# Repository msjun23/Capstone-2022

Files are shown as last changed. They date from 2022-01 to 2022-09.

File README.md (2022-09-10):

# Capstone-2022
Capstone Design at Kwangwoon Univ. 2022

# UMRobot (a.k.a. UMbot)
Universal Mobile Robot Project

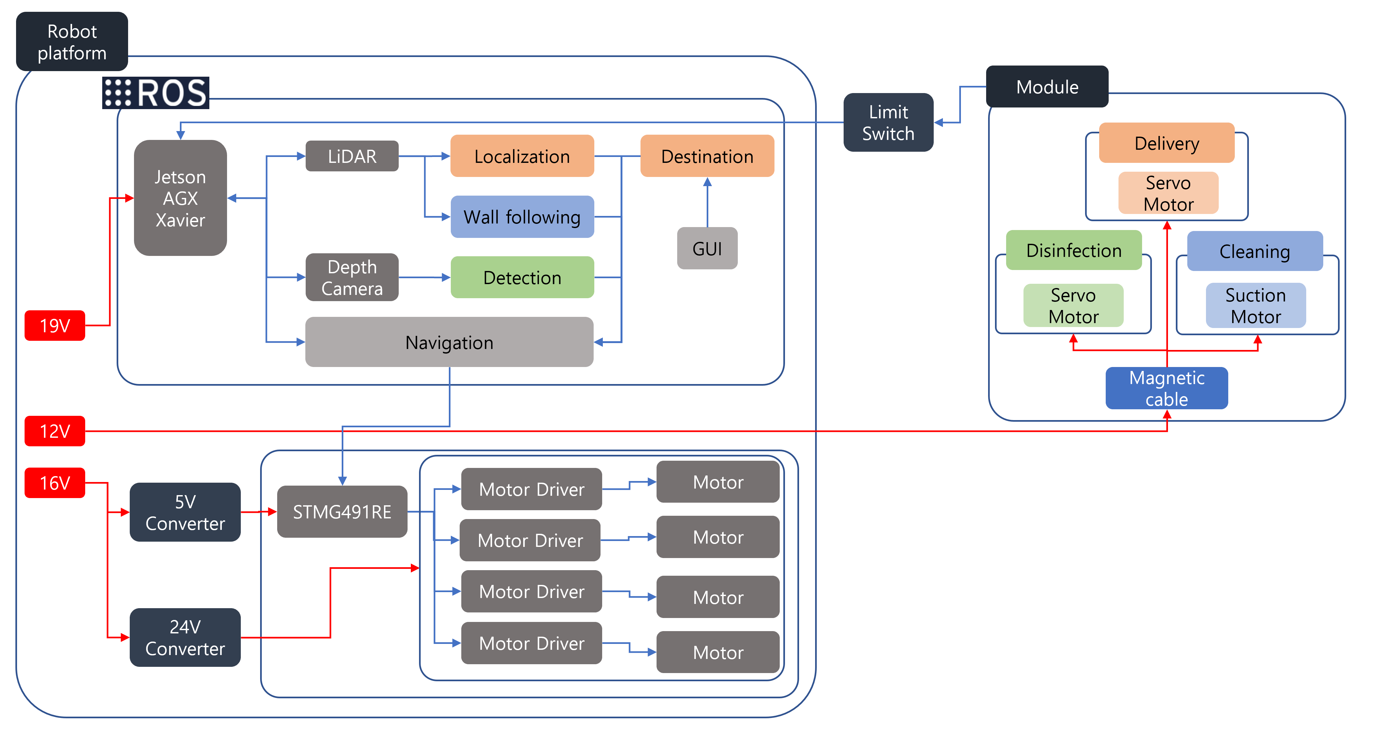
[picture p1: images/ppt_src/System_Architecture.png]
sys_arch


# Git repository
- [ROS Gazebo Simulation](https://github.com/msjun23/umrobot_description)
- [ROS & YOLOv5](https://github.com/msjun23/yolov5_ros)
- [Get door info & pose using camera and LiDAR](https://github.com/csw609/door_angle)
- [Wall following algorithm](https://github.com/msjun23/wall_following)
- [Modules](https://github.com/msjun23/umbot-modules)

# Adviser
[**Junghyun Oh**](http://robotailab.net/people/junghyunoh.html), Prof.
> [RAIL(Robotics & A.I. Lab.)](http://robotailab.net/index.html)
>
> Assistant Professor, School of Robotics, Kwangwoon University

# Team
## HW
- [**Jaewoo Jang**](https://github.com/wodnek1996): Team leader, Motor Control
- [**Taegyeom Gim**](https://github.com/GYEOMGYEOM): Design
## SW
- [**Seokwon Choi**](https://github.com/csw609): SLAM
- [**Seokjun Moon**](https://github.com/msjun23): Detection

---

# Paper
**장재우, 최석원, 문석준, 김태겸, 오정현, "모듈 장착형 다용도 로봇 플랫폼", ICROS2022, Geoje, Korea (Jun.2022) - Poster**

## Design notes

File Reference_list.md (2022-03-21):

# Paper
- [A Comparison of Path Planning Algorithms for Robotic Vacuum Cleaners](https://kth.diva-portal.org/smash/get/diva2:1214422/FULLTEXT01.pdf)
- [Path planning algorithm development for autonomous vacuum cleaner robots](https://www.researchgate.net/publication/269297110_Path_planning_algorithm_development_for_autonomous_vacuum_cleaner_robots)
- [Experience based Domestic Environment and User Adaptive Cleaning Algorithm of a Robot Cleaner](https://ieeexplore.ieee.org/stamp/stamp.jsp?tp=&arnumber=7057525)

# Video link
- [협업을 위한 모바일 로봇](https://www.youtube.com/watch?v=IeyBXzikhD0)

- [메카넘 휠 구동 영상](https://www.youtube.com/watch?v=_tmiu1wpp_E)

- [CES2022 현대차 MobeD](https://www.youtube.com/watch?v=KeVDFvYofks)

- [로봇 청소기 예제: 양정연 교수님 SLAM 수업](https://www.youtube.com/watch?v=VXVn75VXRMM&list=PL3Ax8f2laJ6vU449FdgWlVl2VtizhDIfj&index=13)

# Parts
## Jetson AGX Xavier
[Spec & Documentation](https://developer.nvidia.com/embedded/jetson-agx-xavier-developer-kit)

[Tech Blog](https://developer.nvidia.com/blog/nvidia-jetson-agx-xavier-32-teraops-ai-robotics/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)

[NVIDIA Tutorial](https://developer.nvidia.com/embedded/learn/tutorials)

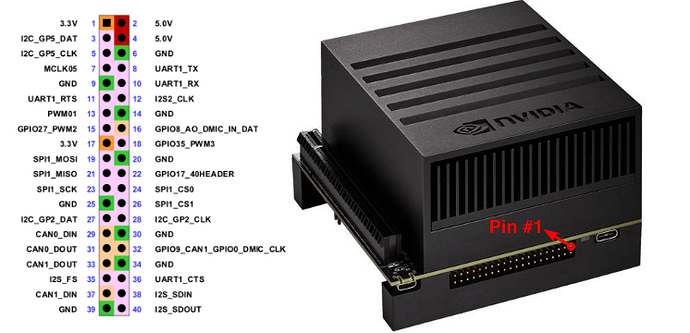
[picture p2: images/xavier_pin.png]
xavier_pin


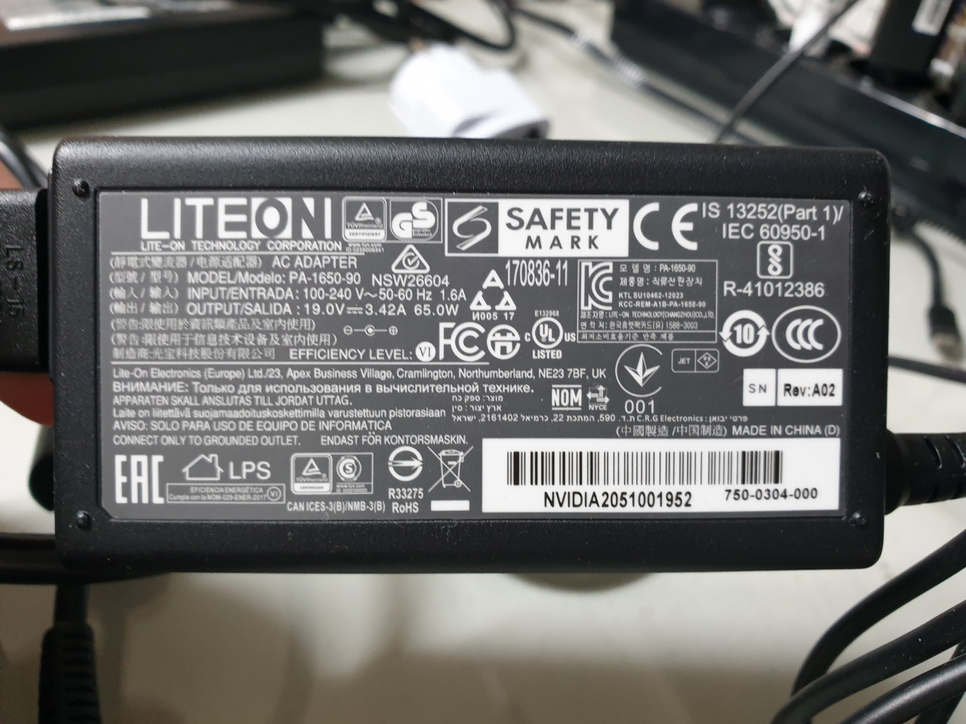
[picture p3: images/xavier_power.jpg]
xavier_power


## Motor
- [IG42GM 02type 24V](https://www.devicemart.co.kr/goods/view?no=1326531)
- 감속비: 1/61
- 18kg-cm // 110PRM // Rated current: 2100mA

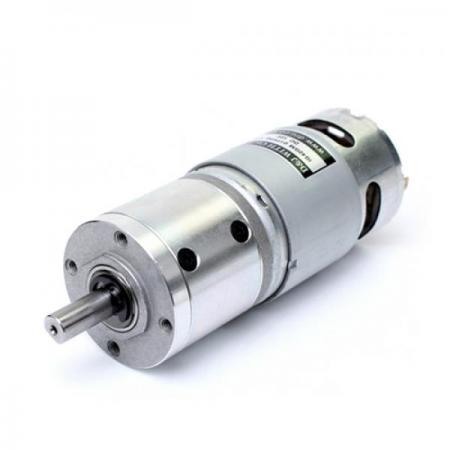
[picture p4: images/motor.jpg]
motor


## Motor Driver
[DCMD-100-P](https://www.devicemart.co.kr/goods/view?no=1266131)

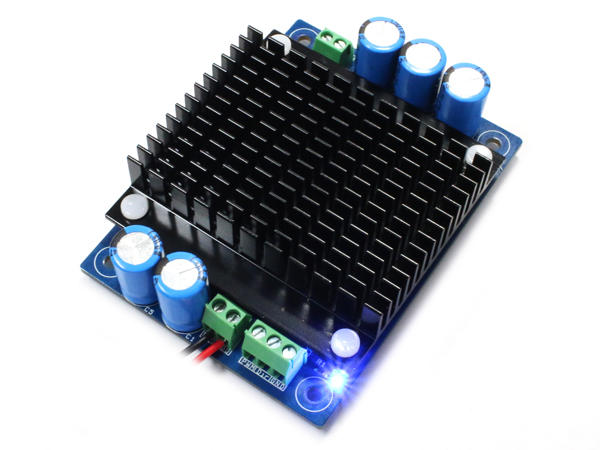
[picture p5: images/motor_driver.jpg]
motor_driver


## Battery
- Jetson
> [노트북 배터리](http://item.gmarket.co.kr/Item?goodscode=1267373161)

- Motor
> 12V, 7400mA, 55C
>
> 12V -> 24V 승압 회로 필요

# Contest Info
## [SRC IRC](http://www.seoultechrobot.com/index.php)

## [KWIX](https://ei.kw.ac.kr/kwix/kwix_18.php)
- 오정현 교수님

## [한이음 ICT멘토링](https://www.hanium.or.kr/portal/hanium/businessOverview.do)
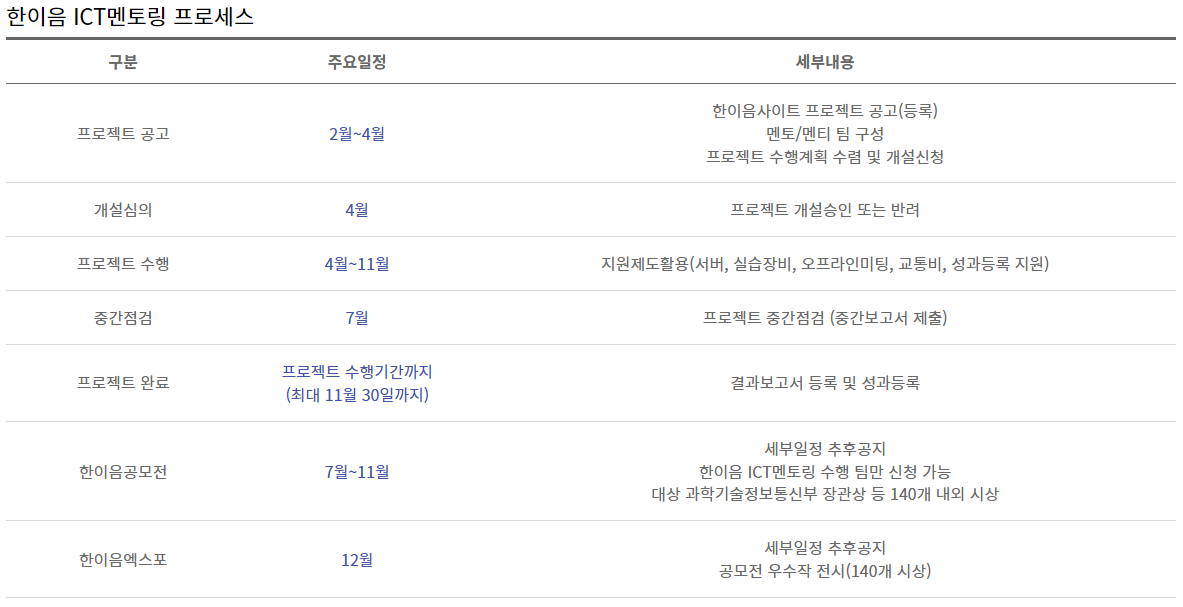
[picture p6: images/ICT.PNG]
ICT


- 멘토: 용호형

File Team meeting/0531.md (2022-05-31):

# 5월 31일

# 최석원, 문석준

- 맵 보안 완료
- 로컬라이제이션 완료
- 방역 모듈 경로 생성까지는 완료
- Jetson AGX Xavier GPIO 세팅 완료
- To do List
    - 방역 모듈 fine control
    - 배달 모듈 실험
    - 청소 모듈 실험

# 장재우

- 모듈 전원 공급 회로 설계 완료
- To do List
    - 모듈별 회로(GPIO, 전원 등) + 아두이노, 모터 등 제작

# 김태겸

- 모듈별 출력 완료
- 로봇 플랫폼에 마그네틱 케이블 설치
- To do List
    - 모듈에 마그네틱 케이블 설치
    - 디스플레이 설치
    - 리미트 스위치 설치
    - 청소 모듈 조립(파이프)

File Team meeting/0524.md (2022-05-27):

# 5월24일

# 김태겸

- 파이프 구매 완료(쉐챌)
- 청소 모듈 포함해서 3D 프린터 뽑을 거 있는데 꽤 오래 걸릴 듯(진행 중)
- To do List
    - 가공 및 조립
    - 마그네틱 설치
    - 디스플레이 설치
    - 리미트 스위치

# 문석준 & 최석원

- 맵 제작
- Vins-Fusion으로 odometry 제작
- 로컬라이제이션 알고리즘 시험
- 어셈블 중
- To do List
    - 맵 보완
    - 로컬라이제이션
    - 방역 모듈(SW) 실험
    - 배달 모듈(SW) 실험
    - 청소 모듈(SW) 실험

# 장재우

- 패킷 통신 완료
- To Do List
    - 모듈 전원 공급 회로 설계

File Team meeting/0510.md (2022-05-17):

# 문석준

- jetson 초기화, 복구 완
- 내비게이션 완
- 매핑 잘돼고
- 석원이랑 합치면 될듯
- 골 포인트를 UI 에서 좌표 형태로 pub하도록 하면 됨
- detection부 디버깅 중(해결하면 위 사안으로 넘어갈 예정)

# 최석원

- 방역 모듈, 기존 모듈 디버깅
- 석준이랑 합치기
- outlier 제거는 문 인식x → 문고리 인식 후 실험 필요
- 로봇 완성 후 실험 필요

# 겸겸스

- 방역, 배달 모듈 부품 가공 중(파츠 나눠서)
- 서스펜션: 수정 필요(재가공)
- 카메라 마운트, 디스플레이 마운트 회사에서 가공 예정

# 장재우

- 전류 제어 이슈
- 전류 제어 → 속도 제어

# To Do

- SW 융합 및 디버깅
- 제어 이슈 처리

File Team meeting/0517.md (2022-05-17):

# 장재우

- 제어기 완료
- To do list : ROS to stm32 board
- To  do list : 19일 이후 모듈 전원 공급

# 문석준

- 방역모듈 3D 프린터 다 뽑앗고
- To do list: 어샘블해야 됨
- To do list : 아두이노 만져보기

# 최석원

- 소프트웨어 진행사항은 없음
- 실험 도움, 메카넘 휠 바퀴 망가진 것들 고침
- To  do list : 맵 제작, 알고리즘들 로봇에서 테스트

# 김태겸

- 5월 17일 : 배선 정리, 라이다, 카메라
- 5월 18일 : 파이프 구매
- 5월 19일 : 마그네틱 설치
- 주말까지 : 디스플레이(VESA 규격: 75 * 75)  마운트 설계
- 주말까지 : 청소 모듈 설계
- 서스펜션은 제작 취소 // 완성 후 서스펜션 추가

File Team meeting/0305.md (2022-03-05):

# KWIX
- 개인 서명 필요

# 한이음 ICT 멘토링
- 멘토 정하기

# 일정
재우-월화수목금토일
석준-월화수 (토일 간헐적)
석원-월화수 (토일 간헐적)
겸겸-화목 (부르면 옴)

# 석준
- 문과 작업
- 프로젝트 

# 겸겸스
- 서스펜션 설계까지 완
- 로빛이랑 얘기해서 담주나 다담주 쯤 가공 시작
- 이번 달 안까지 메인 완성 목표

# 석원
- Point cloud -> 필터링 후 평면의 방정식 구함
- ROS 상에서 GUI 구현

기능은 어렵지 않을 듯

# 재우형
- IG42GM 02type 24V
- encoder 바꿀 수도 있음

# To Do & Consider
- 문, 문고리 detection 후 위치 pub, 수요일 쯤 석원, 석준 퓨전 목표
- 담주나 다담주 쯤 가공 시작 (3월 10일 쯤?)
- 겸겸스가 모터까지 추가해서 모델링
- 석준: 청소 모듈 path planning 조사
- 전체 회로 제작
- 캡스톤 비 구매
- wasd -> 모터 제어
- 다음 교수회의는 14, 15, 16?

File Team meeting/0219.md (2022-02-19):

# 재우형
- Jetson Xavier -> 노트북 보조 배터리 (10만원)
- 24V 배터리(~20만원)
- 12V 배터리면 좀 만만함
- ~~엘리베이터~~
- Dynamics 진행 중

---

- load 20kg
- 메카넘휠 radius
- torque 48kg-cm는 나와야 여유로울 듯

## 범수형네
- 캡스톤 load < 8kg

# 겸겸
- new 설계 중
- AK80 안됨

# 석원
- RGB 이미지 상에서 bounding box 전달 받아서 point cloud 상에서 crop(?), plane segmentation

# 석준
- 문 데이터 셋 찾기
- 문 데이터 vs 문고리 데이터 셋
- segmentation도 한 번 고려만 해보면 좋을 듯

# To Do & Consider
- 24일 날 교수님 미팅 잡아봄
- 임베디드 프로그래밍(하위 제어)
- **모터 선정**
- **사비 털어야 됨**
- **모터 하나 ~20만원 정도**
- 각자 개인 계획표 세워오기
- 개인 계획 조율 -> 전체 계획

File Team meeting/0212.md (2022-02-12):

# 재우형
- 메카넘휠 dynamics 해석

로봇운동학 짱짱맨

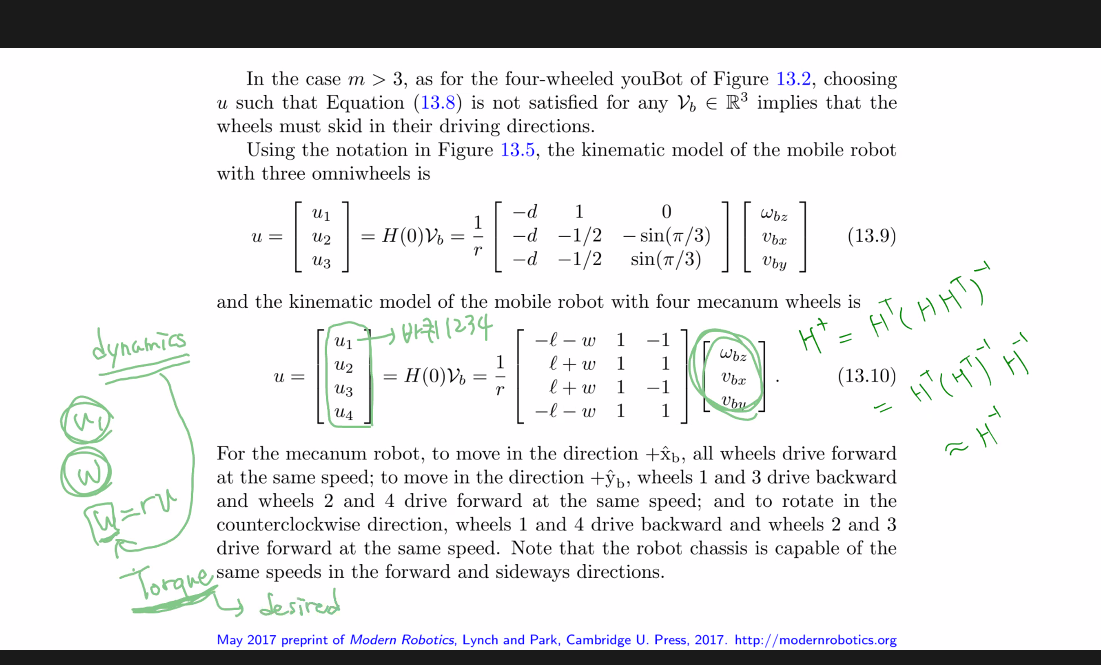
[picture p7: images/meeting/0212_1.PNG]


- 길 안내 모듈
> 길 안내(for 실버)
>
> UI 존재

# 석준
- 반려견 cctv 모듈
> 가정집 등 로봇의 적용 범위를 넓혔다.
>
> tracking 퍼포먼스

# 석원
- **청소 모듈**
> **로봇 청소기의 기능을 먹어버리자**
>
> 구현도 나름 쉬움

- SLAM
> Visual SLAM -> z axiz error
>
> 2D LiDAR SLAM이 더 좋을 것 같음
>
> 카메라는 detecting 한 객체를 맵에 등록하는... 공부를 해야겠다.

# 겸겸
- 배달에 로봇팔 추가한 모듈

- **D435i 50% 가능**

- **2D, 3D LiDAR 가능**

- 마그네틱 커넥터 배송 중

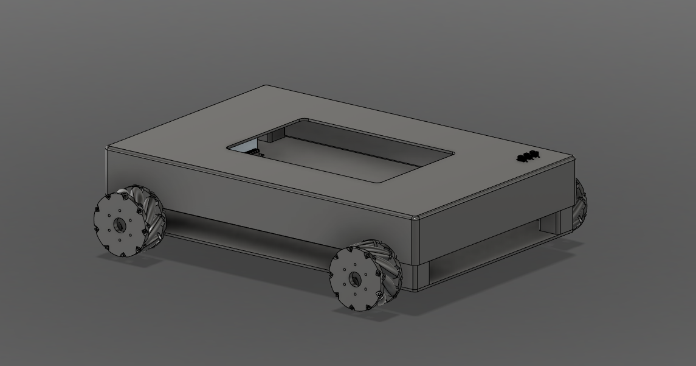
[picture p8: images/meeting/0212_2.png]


위 그림에서 위, 아래 층 바꿈

# To Do & Consider
- 문, 문고리 detection
- detected object를 맵에 등록?
- 모터 선정
- 설계, 서스펜션
- **24일에 하드웨어 보기**

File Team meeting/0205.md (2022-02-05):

# 모듈

## 석원

- 방역 모듈 -> 높은 높이, 서랍 가장 위 층

카메라 방향과 같은 방향으로 소독기 등 배치

탈부착이 가능한 작은 크기의 방역모듈

2층 서랍장 같은 기본 프레임 -> 서랍처럼 모듈을 끼고 뺴고

> **기본 Design: 서랍장**: 서랍을 바뀌는거에 따라 모듈이 바뀌는
>
> **각각의 모듈은 하나의 서랍**

- 배달 1 -> 사무용품 배달
- 배달 2 -> 식음료 배달
> 석준 둘이 비슷한것 같아서... 둘이 합치는게 나을 것 같음

- 방역 모듈을 위로 길게 뺸다면 -> 모듈화에 의미가 더 있지 않을까

## 재우형

방역: task 구현이 어렵지 않을까

무히려 방범이 더 쉬운 구현?

모듈의 갯수

## 석준

모듈은 구현은 간단하게 -> **모듈화라는 아이디어**를 보여줄 수 있을만큼

- 배달
- 서빙
- 방역

라이다랑 카메라랑 달 위치 고려

> LiDAR는 차체 아래에 공간을 내서 설치
> 
> 카메라는 ~~T265~~ / D435i

## 겸겸

설계 네이스

**마그네틱 케이블 규격화**

# 결정
- 카메라, LiDAR는 베이스에 다 때려박음 -> 겸겸스 설계 필

- 배송(일반 / 식음료)

- 방역

- 1개 더

# To Do & Consider
- KWIX 3월 전에 마무리
> 대회는 틈틈히 조사

- 부품 공수
> AK80-9
>
> 모터드라이버
>
> 전류센서
>
> 마그네틱 케이블(구매처)
>
> D435i 겸겸스네
> 
> LiDAR
> 24V, 12V 배터리
>

- 1인 1모듈, 차별적, 혁신적 생각하기

- 겸겸스 공수 여부에 따라 담주 회의 때 필요 물품 구입

- 재우형 -> 겸겸스 부붐과 유기적으로 회로 설계

- Dynamics, 제어 파트 로드맵

- Demo SLAM, Demo Detection(데이터 셋 조사: 문고리)

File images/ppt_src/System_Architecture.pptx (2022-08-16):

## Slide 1

Robot platform

Jetson AGX Xavier

Module

LiDAR

Localization

Destination

Limit Switch

Delivery

Servo Motor

Wall following

Depth Camera

Detection

GUI

Disinfection

Servo Motor

Cleaning

Suction Motor

19V

Navigation

12V

STMG491RE

Magnetic cable

16V

5V Converter

Motor Driver

Motor

Motor Driver

Motor

24V Converter

Motor Driver

Motor Driver

Motor

Motor

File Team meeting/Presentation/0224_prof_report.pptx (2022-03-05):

## Weekly Report

2017741025 장재우
2017741052 최석원
2016741012 문석준
2017741021 김태겸

Feb 24, 2022

## Index

- Project Concept

- 1

- 2

- Progress

- 3

- Schedule

- 4

- KWIX

- 5

- System Architecture

## Project Concept

- Problem about existing robots
  - One robot, one purpose
  - Fixed hardware, low adaptability

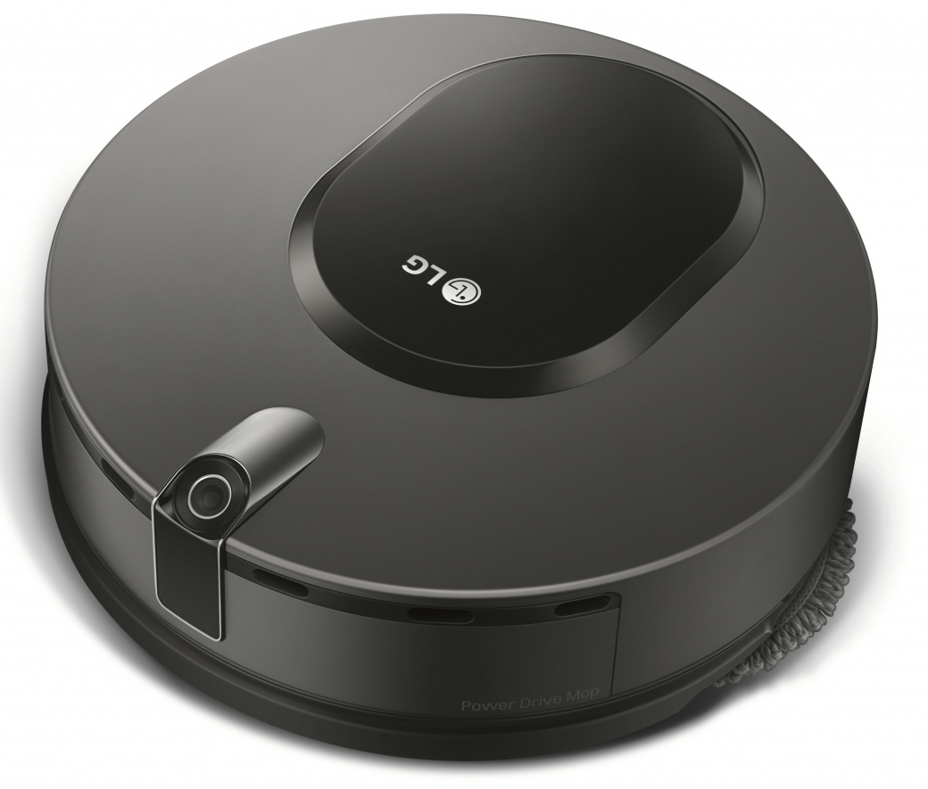
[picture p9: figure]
LG전자, 물걸레 전용 로봇청소기 출시 &lt; 가젯·컨슈머 &lt; 라이프 &lt; 기사본문 - 테크월드뉴스 - 김경한 기자
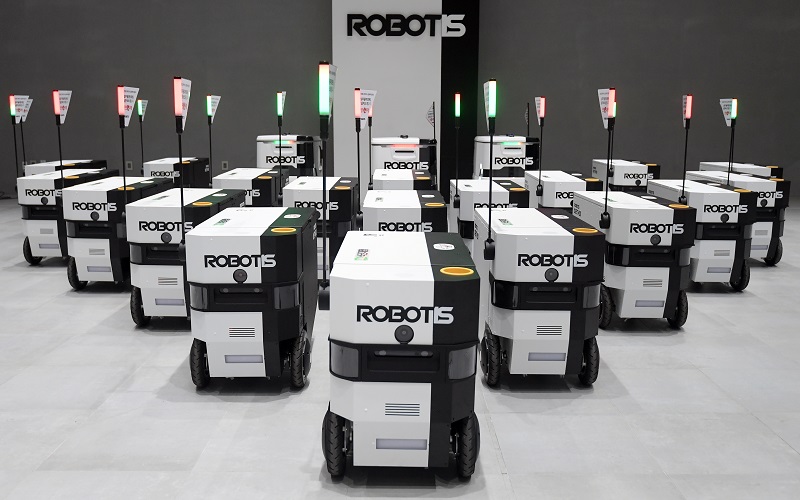
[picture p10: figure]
로보티즈, 일반 자율주행 로봇 배송 서비스 실시
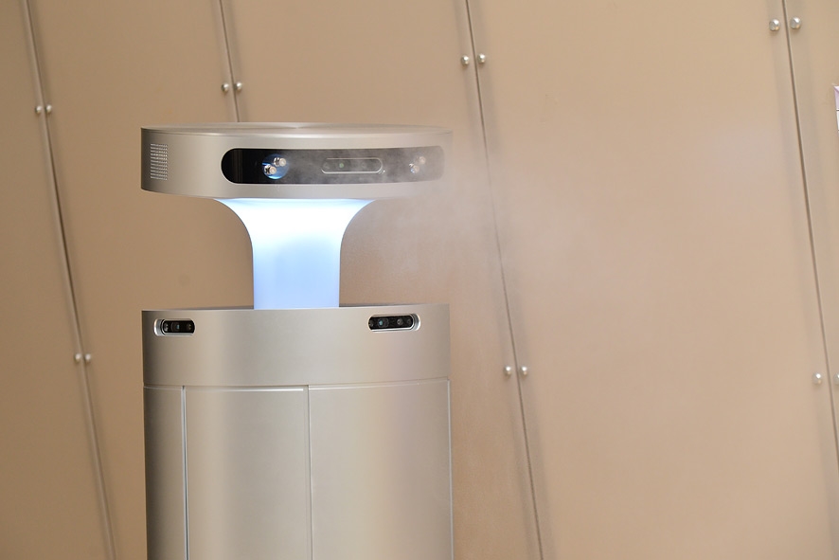
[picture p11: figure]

## Project Concept

- Proposal
  - One robot, many possibility
  - Changeable hardware, high adaptability
  - Robot platform + modules

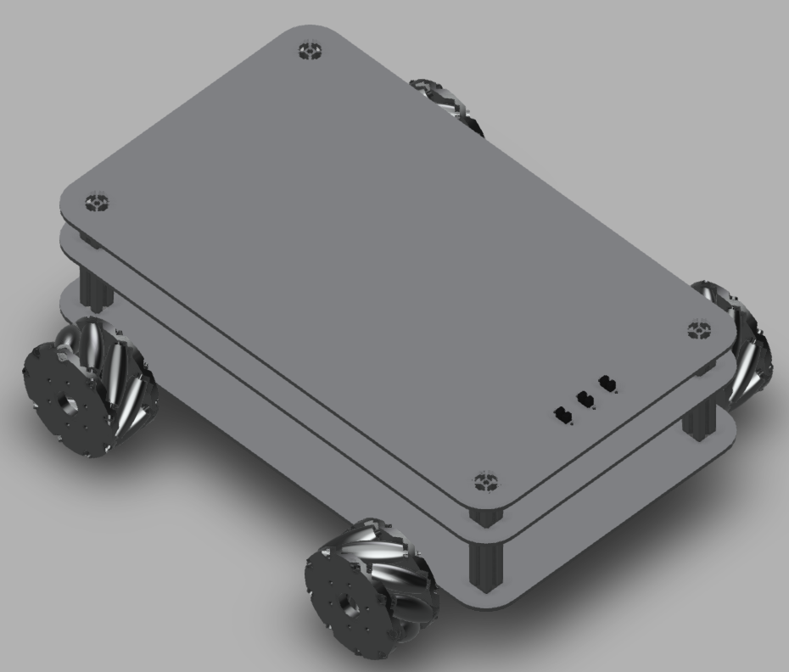
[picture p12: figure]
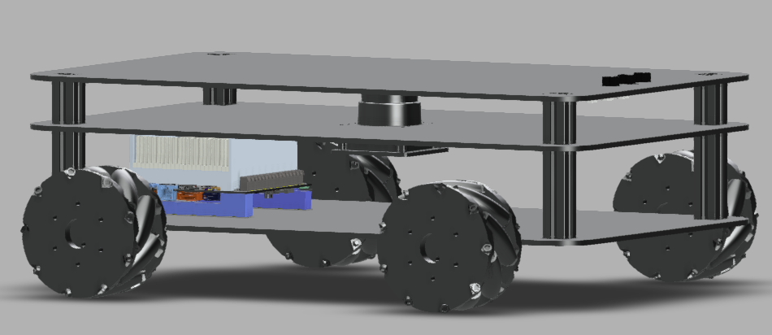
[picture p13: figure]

## Project Concept

- Robot platform
  - Jetson AGX Xavier
    - Powerful GPU performance, fast computational processing power
  - LiDAR + Depth camera
    - SLAM & Detection based autonomous actions
  - Mecanum wheels
    - Move in all directions easily
  - Easy to connect modules
    - Use the limited switch to find out what module is connected
    - Power supply to the module using magnetic cable

## Project Concept

- Modules
  - Delivery
    - Get user input by GUI
    - Localization & navigation to the goal
  - Disinfection
    - Move around and detect door & doorknob
    - Spray disinfectant to doorknob
  - Cleaning
    - Global exploration based on wall following algorithm
    - Cleaning floor

## System Architecture

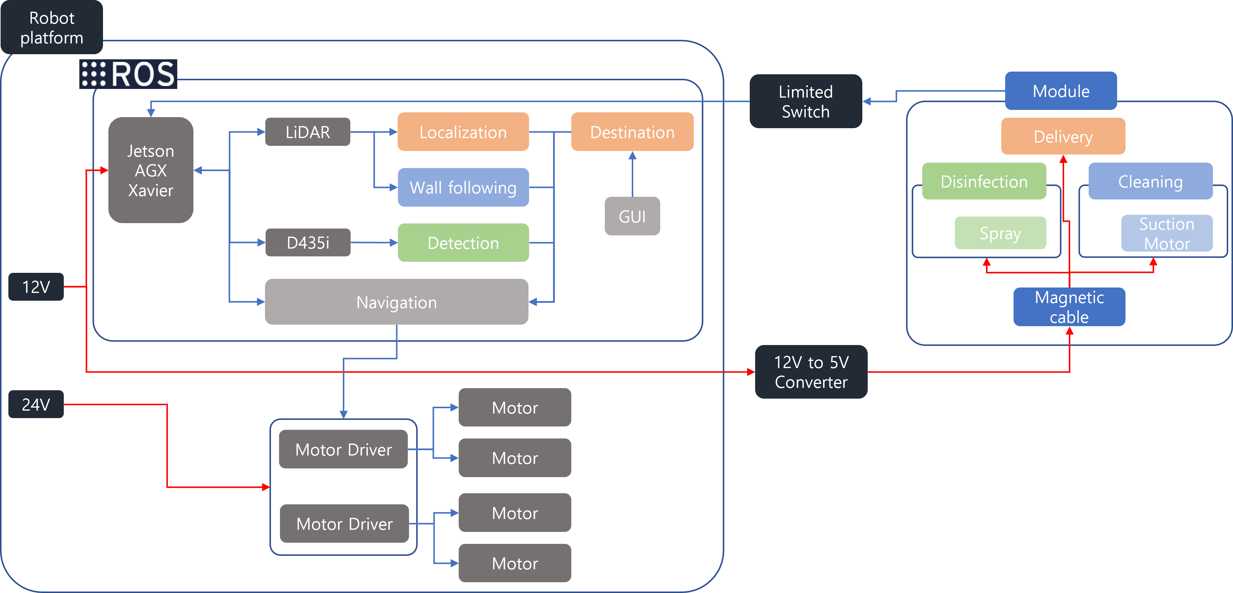
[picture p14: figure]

## Progress

- Hardware Design
- Mecanum wheel kinematics
- Detection using YOLOv5
- Show bounding box on point cloud map

## Progress

- To do
  - Motor selection
  - Consideration about suspension
  - Case design
  - Module design
  - Consideration about motor controller
  - Find or make doorknob dataset

## Schedule - HW

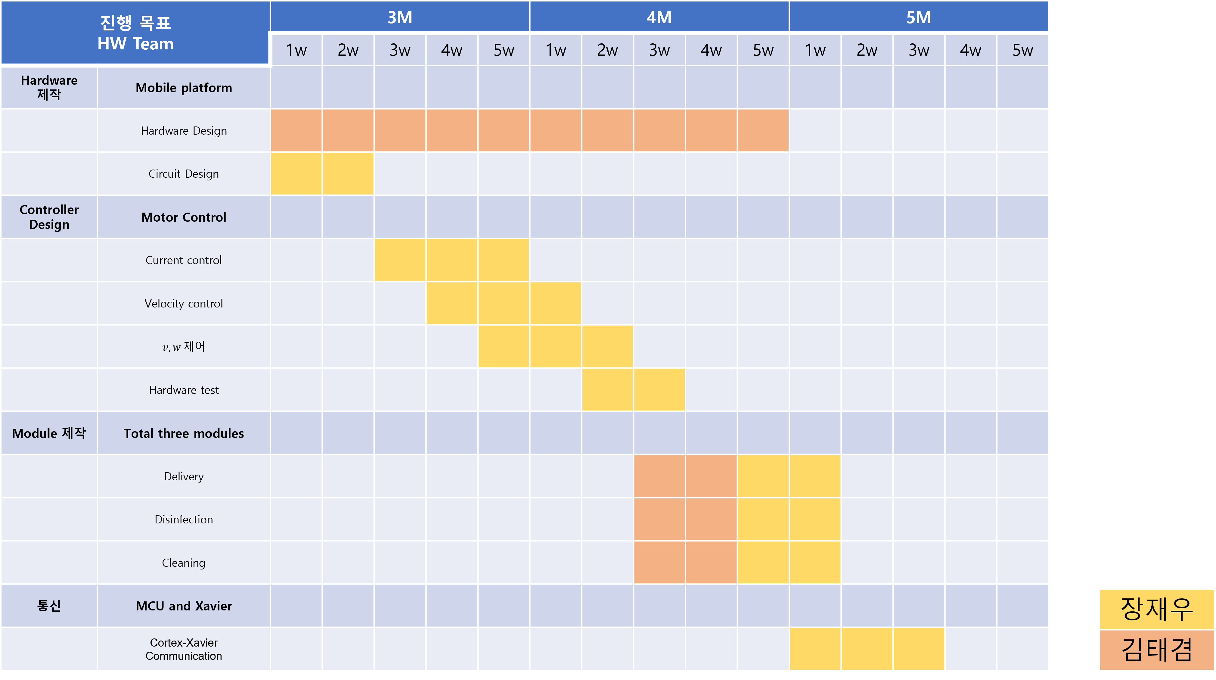
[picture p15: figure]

## Schedule - SW

## KWIX

## Q&A

Thank you

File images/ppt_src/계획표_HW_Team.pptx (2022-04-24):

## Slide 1

진행 목표 HW Team | | 3M | | | | | 4M | | | | | 5M
| | 1w | 2w | 3w | 4w | 5w | 1w | 2w | 3w | 4w | 5w | 1w | 2w | 3w | 4w | 5w
Hardware 제작 | Mobile platform
| Hardware Design
| Circuit Design
Controller Design | Motor Control
| Current control
| Velocity control
| v,w 제 어
| Hardware test
Module 제작 | Total three modules
| Delivery
| Disinfection
| Cleaning
통신 | MCU and Xavier
| Cortex-Xavier Communication

장재우
김태겸

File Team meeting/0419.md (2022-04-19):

# 재우
- 회로 완
- 모터 제어 진행 중

제어 주기, PWM 생성 -> 제어 식 코딩 필요(본격적)

Notion 확인 필

# 석준
- Wall following 알고리즘 틀은 잡았고,
- 석원이와 동시 진행 중인 내용에 대한 이슈 해결 필요
 
 이미지 resize 412\*412 -> 640\*480

 bb hz 확인 필

- 매핑 필 -> Cartographer

# 석원
- 문 각도 구하는 노드 내에서 문을 가르키는 scan 포인트로 문 각도 구함

문에 대한 정보 저장, 로드하는 내용 구현 -> 실험, 디버깅 필요

- 문 각도 -> 로봇의 pose 추출 및 publish 하는 노드 작성 중

# 겸겸
- 서스펜션 테스트
- 구상 완
- 로봇에 들어가는 세부 부품(포고 핀, 스위치) 고정할 프레임 설계

# 대회
- KWIX는 답이 없음

결재 진행중이라는데 빠르면 내일 답이 나온다는데 허허;

- 한이음
보고서 달마다

4/26일까지 실습 장비 신청

최대 130만원, 5번까지 신청 가능

# 모듈 디자인
- 아두이노 사용

통신: STM <-> 아두이노

- 배달 모듈 -> 서보 모터로 뚜껑 열어주기
- 방역 모듈 -> 서보 모터로 스프레이 뿌리기
- 청소 모듈 -> 흡입 모터 사용, 세부사항은 서치

# 소핑
- 포터블 모니터

---

- 아두이노 우노
- 점퍼선
- 프로파일 캡

# To Do
- 각자 일정 진행
- 상판 디자인 맞춰서 세부 부품 조립 필
- 모듈별 설계

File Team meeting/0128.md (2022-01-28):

# 메카넘휠 + 겸겸스 리뷰 + (캡스톤 이후 대회 or 개인)

# 메카넘휠
> 쓰는거로 확정

## 석원

HW팀에 전적으로 위임

그래도 메카넘 휠이 기동성에 더 좋지 않을까

센서에 진동이 없으면 좋을것 같아서 서스펜션 굿

## 재우형

- **메카넘휠** -> 4륜

근데 짜피 로빛에 있는게 4개

방향 자유자재, 제자리 회전 가능

제자리 회전을 통해서 카메라 시야각 넓힐 수 있지 않을까

- 일반 휠

2륜은 갓승완네가 해봤을 때 잘 안된다고 했음

4륜도 어렵지 않을까?

~~6륜~~

조향각 들어가는 순간 좀 어려울 것 같음

무게 고려했을 때 서스펜션 굿

**실내 회전하기 어려운 좁은 공간 -> 메카넘휠이 나을 것 같음**

## 석준

2D LiDAR, Depth, Tracking Camera 다 쓸 생각

서스펜션 다 해야한다고 생각

## 겸겸

로빛에서 공수

서스펜션

# 겸겸스 리뷰, 마그네틱 커넥터

~~마그네틱 연결만 되면~~

모듈 전원 넣기 위해서 마그네틱 커넥터는 써야한다.

리미티드 스위치 사용

**모듈 연결부에 구멍을 다르게 뚫어놔서 플랫폼에 꽂았을때 서로 다른 스위치가 눌리게해서 어떤 모듈이 연결됐는지 확인**

모듈에 대한 아이디어 회의 필요

지금까지 나왔던게 방역, 에어컨, 배송, 방범, 위생, 수송 등

# 캡스톤 이후 대회 or 개인

- **KWIX 확정**
- 유지, 보수
- 어떤 대회가 있을까
- KIRC
- SRC IRC
- 한이음 == 지역밀착
- 임베디드 SW 경진대회
- 스팀컵(?)
- 창업 경진(?)

최대한 버틸 수 있는 만큼 나가는걸로

# To Do & Consider

- 모듈 아이디어 및 구현 방식 및 시나리오

- 모듈 이상치 3개, 최소 2개, 여유가 되면 하나 더 ㅋㅋ

- 마그네틱 커넥터 제품, 작동 방식 등 조사

- 부품이랑 보드 및 기자재 확정, 공수(가능한)

- 대회는 틈틈히 조사

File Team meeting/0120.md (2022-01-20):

# **Professor Advice**

# 메카넘 휠이 적당한 contribution을 가지는가?
- 메카넘 휠에 대한 타당성 검증 필요

- 실내 환경에서 메카넘 휠에 대한 효율 및 실제 사용 사례 등 조사가 필요할 것 같음

# Idea Compensation
> ex) 현대 차, [MobeD](https://www.youtube.com/watch?v=KeVDFvYofks)
> 
>> **Mobile Robot Platform**
>>
>> **\+**
>>
>> **Service Module**
>
> 기반을 만들고 그 위에 뭘 올리는지에 따라 용도, 역할이 바뀜

- 다양한 서비스(배달, 방역, 공기 청정 등)를 제공하는 모듈을 장착할 수 있는 하나의 모바일 로봇 플랫폼 제작

- 즉, 여러 모듈을 갈아낄 수 있는 하나의 모바일 베이스 제작

*ex1.* 모바일 베이스에 배달용 컨테이너 모듈을 올리면 배달 로봇으로 활용 가능

*ex2.* 방역 모듈을 올리면 주기적으로 돌아다니며 방역에 관한 task 수행

*ex3.* 공기 청정 모듈을 올리면 이동 가능한 공기 청정기 로봇 -> 리프팅 구조를 추가해 높이에 따른 공기 청정 기능 제공도 가능(주방 등)

# Detailed role
## HW Team
- 기존 제품 모듈화
- 모바일 베이스에 장착 가능하도록 모듈화 구현
- 혹은 서비스 모듈 제작

## SW Team
- 장착된 모듈 인식
- 모듈에 따라 각기 다른 움직임, 메커니즘 구현

# + &alpha;
- 여러 모바일 로봇 베이스의 협업 가능성
- 더 크거나 무거운 물건을 옮기는 등의 task를 수행하기 위해 여러 베이스 로봇의 협동
- Multi Robot Control

# To Do & To Consider
- 실제 사용할 센서, 모터 등 조사
- 개발비 충당 방안 조사(대회, 공모전)
- 랩실 차원에서 지원 불가, 랩실 부품 등 테스트를 위한 일시적 대여는 가능하나, 최종 개발은 스스로

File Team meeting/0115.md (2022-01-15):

# 실내 모바일 로봇 컨셉 & 시나리오 확정

## 석원 - 실내 서비스 다 때려박아
- 방역, 심부름, ~~안내~~

모바일 로봇에 공기청정기도 넣고 배달 칸도 나눠서 뭐 서류 배달도 가능하고

음식 배달도 해주고 문고리 인식해서 문도 열고
지도를 통해서 사람을 안내해주는 것도 있고
서랍처럼 위아래로 길게 디자인

택배, 기타, 음식, 서류 넣는 칸

손 세정제, 소독제, 다 때려박아 -> 문 손잡이 인식, 이동해서 소독액 분사

## 재우
- 옴니 휠

- 충돌 회피

- 그럼 심부름만 디테일하게

심부름꾼, 짐꾼(따르고)의 디테일을 살림

## 석준
- [옴니휠인모터 플랫폼](http://www.motor114.co.kr/product_list.php?ca_id=206070)

- 사람 인식

사람을 인식해서 중간에 만나면 굳이 장소까지 안가고 바로 물건 전달

ex) 322호 문석준한테 보내줘! -> 322호까지 안갔는데 문석준을 만남 -> 바로 전달하고 돌아감

- *자동 충전*

로봇이 자동 충전소로 정확히 들어갈 수 있나...

충전소 근처에서 QR이나 라인트레이서 방식을 더해서 충전소 주차 안정성 **up**

- 단층 리프트

겸겸스 링크 초반에 나오는거처럼

## 겸겸
[택배 위아래로 움직이는](https://www.youtube.com/watch?v=IeyBXzikhD0)

- 택배 관련 아이디어

택배를 쌓아서 한 번에 배달

택배 기사의 일을 줄이자

---

# 기능 우선순위

1. 심부름

2. 방역

3. 추가 시나리오, 사람 인식

---

# 오정현 교수님과 미팅

1. 메카넘 휠 (**로봇 플랫폼 사줘 응애**)

2. 하드웨어, 리프팅 구조 / 2층 적재함

3. 심부름 집중(사람 인식: 따라가는거, 인식 해서 물건 전달해 주는거) / 심부름 + 방역

4. 시나리오

---

# 시나리오
## 심부름
1. 충전 위치에 항시 대기 (ex. 엘베 앞)
2. UI를 통한 심부름 요청 입력
3. 로봇 목적지까지 이동 후 임무 수행 완료
4. 충전 위치 복귀
(5. 수령인을 먼저 만나면 임무 완료 후 복귀)

# 시나리오2
## 방역
1. 심부름 요청이 10분 이상 없을 경우 or 특정 시간대 (로봇이 여유로울 때)
2. 방역 실시
3. 문손잡이로 이동, 소독

---

# 다음 회의

- 재우, 겸겸 -> 메카넘 휠 비용이나 설계, 제어 가능성 조사 (로빛)

- 석준 석원 -> SLAM, 카메라, LiDAR, IMU 등 장비, 디텍션 방식, 전체 프로세싱 구상

- 오정현 교수님 미팅 준비 -> 간단한 시각화 자료 준비 필요

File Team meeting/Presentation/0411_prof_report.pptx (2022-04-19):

## Weekly Report

2017741025 장재우
2017741052 최석원
2016741012 문석준
2017741021 김태겸

Apr, 11 2022

## Index

- HW

- 1

- SW

- 2

- 진행 일정

- 3

## HW

- Robot platform
  - Embedded 보드 회로 설계
  - 모터 드라이버, 엔코더 및 전류 센서 모듈 설계

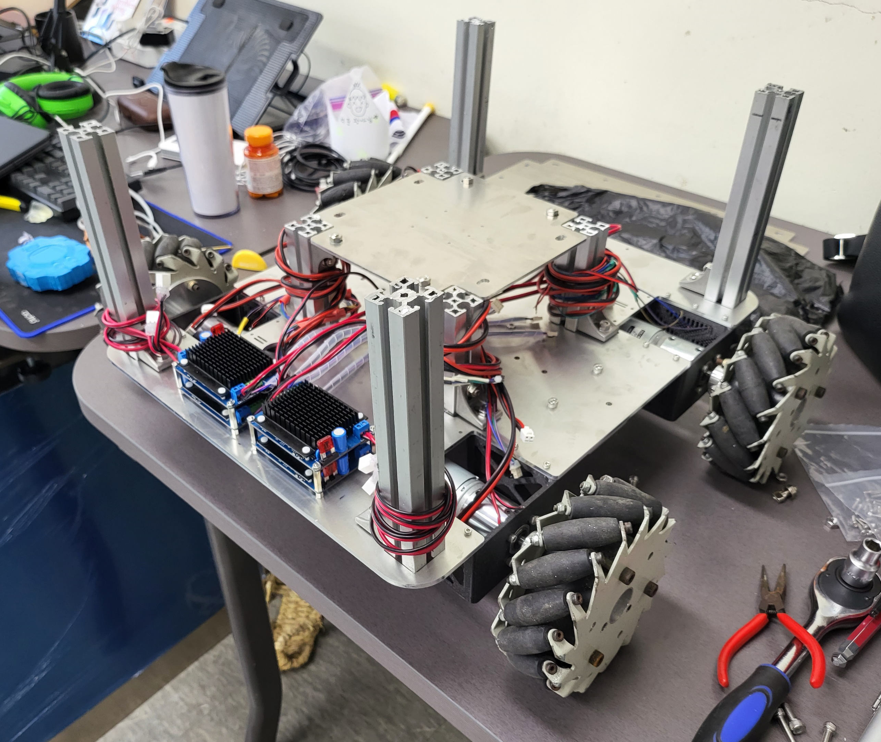
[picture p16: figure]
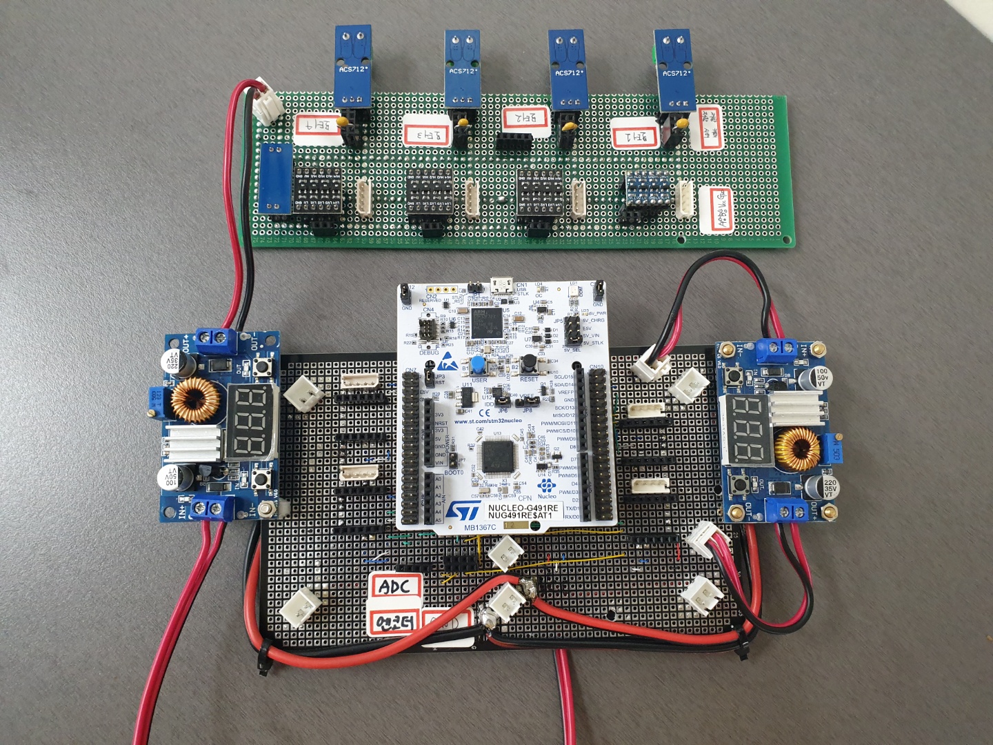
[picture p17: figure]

## SW

- Gazebo Simulation
  - 누리관 .world 제작
  - YOLOv5 & TensorRT 적용 -> 문 검출
  - 카메라, LiDAR 퓨전을 통한 bounding box 위치 검출

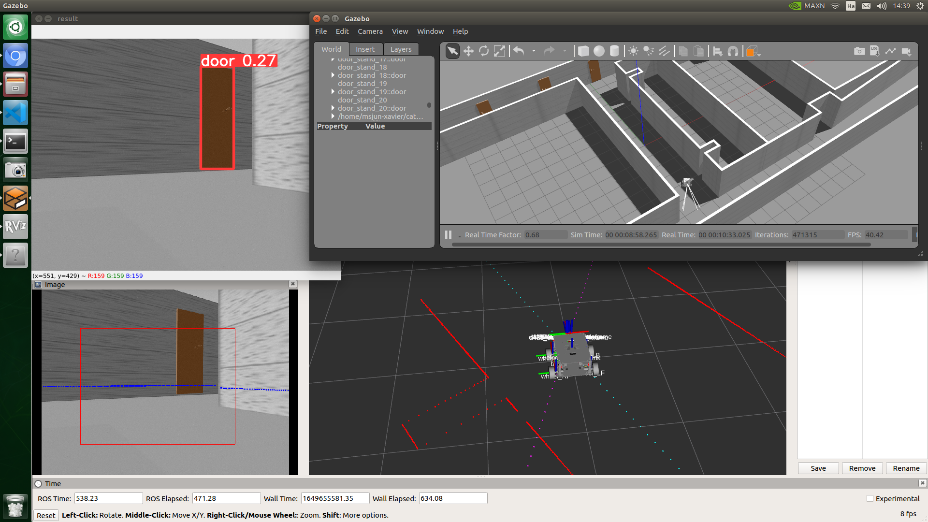
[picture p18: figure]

## Schedule - HW


## Schedule - SW

## Q&A

Thank you

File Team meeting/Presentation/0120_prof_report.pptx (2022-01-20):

## Weekly Report

2017741025 장재우
2017741052 최석원
2016741012 문석준
2017741021 김태겸

## Index

- Mecanum Wheel

- 1

- 2

- 3

- Scenario

- 4

- Hardware Design 1

- Hardware Design 2

## Mecanum Wheel

- Movements to any directions
- Easy to rotation in place

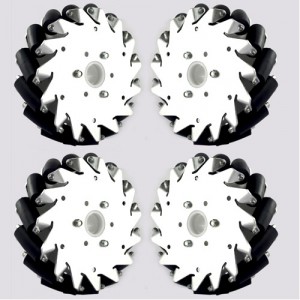
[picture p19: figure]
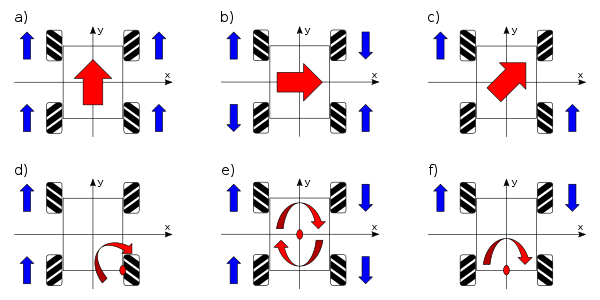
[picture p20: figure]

## Hardware Design 1

- Problem about existing robots
  - One robot, one purpose

로보티즈, 일반 자율주행 로봇 배송 서비스 실시

## Hardware Design 1

- Delivery + Disinfection = Focus on Multipurpose
  - Delivery
    - Food, paper or some packages
    - Separated container
      - Food
      - Package or paper(no food)
  - Disinfection
    - Air cleaner
    - Detect doorknob and spray disinfectant

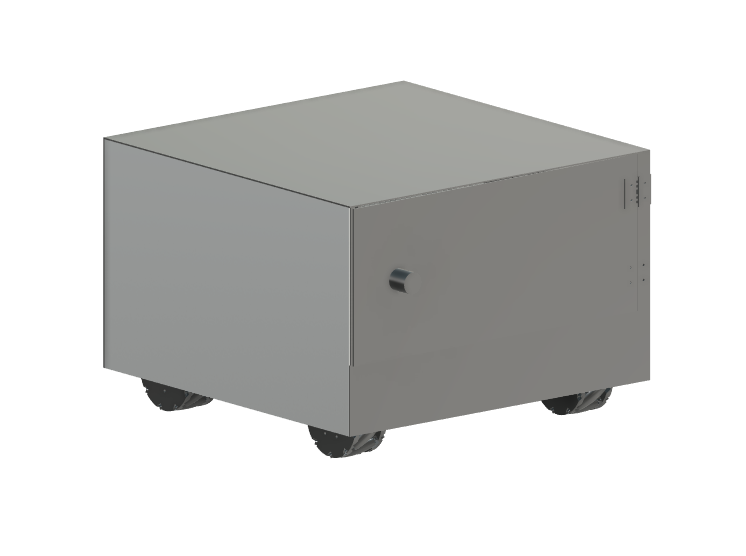
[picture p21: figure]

Spray
+
Air cleaner

Spray
+
Air cleaner

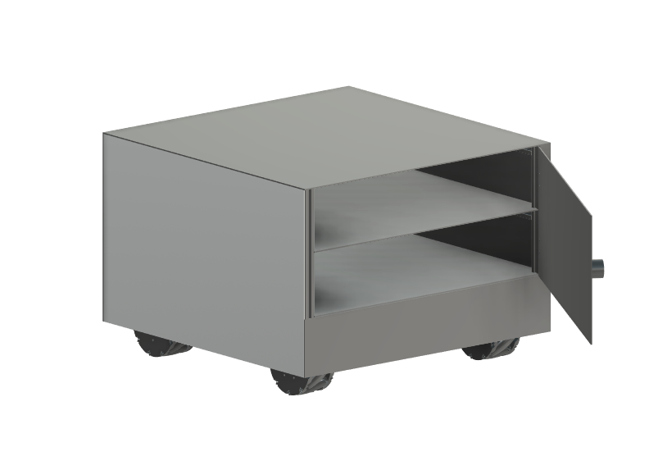
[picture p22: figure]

## Hardware Design 2

- Problem about existing robots
  - Fixed hardware and uncomfortable pose

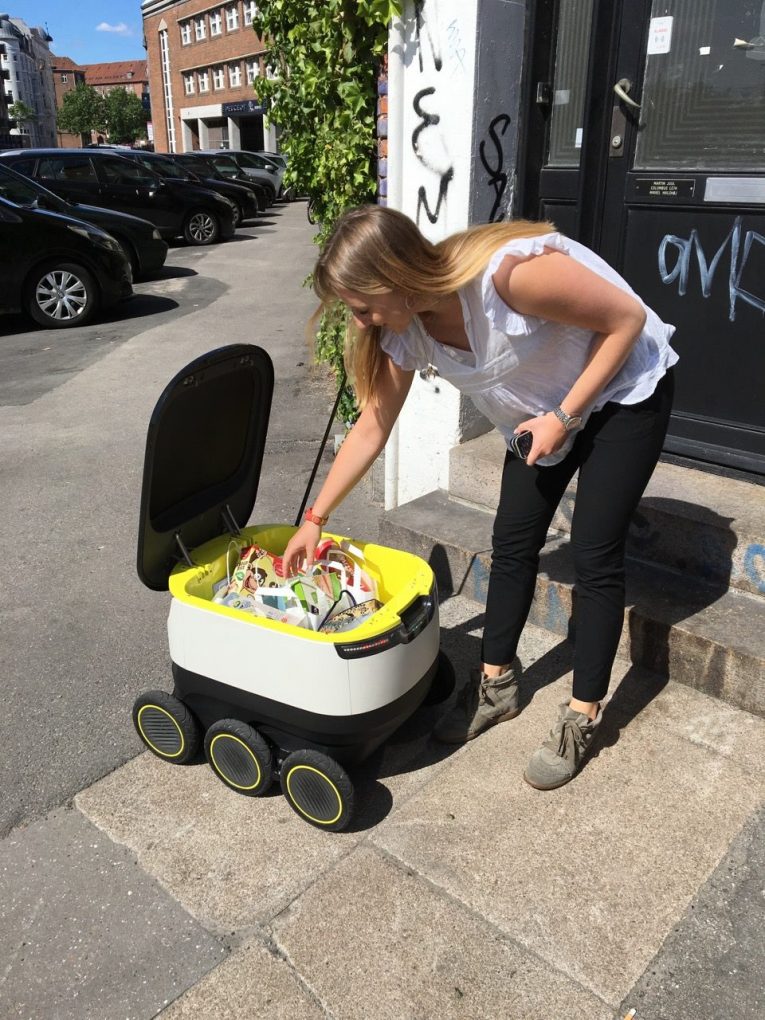
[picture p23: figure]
음식 배달 로봇 상용화 : 한글과컴퓨터
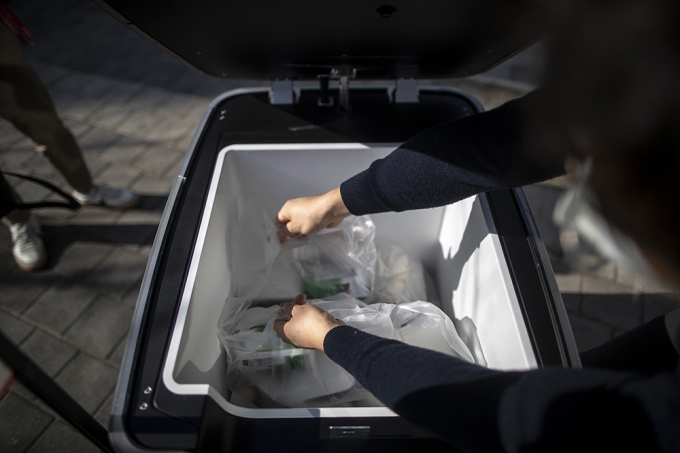
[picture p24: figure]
사진 세상] &quot;이젠 음식 배달도 자율주행 로봇에 맡기세요&quot;
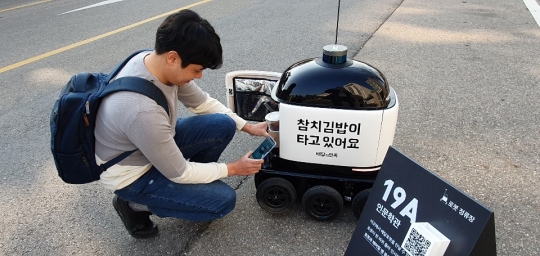
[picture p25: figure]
르포) 배달의민족 &#39;캠퍼스 로봇&#39; 절반의 성공, 로봇 오퍼레이터 없이 혼자 주행해야

## Hardware Design 2

- Focus on just Delivery and Usability
  - Liftable container
    - While moving
      - Lift-down container
      - Sustain stability when moving
    - While put on / pick up
      - Lift-up container
      - More convenience for user


package


package

## Scenario

- Common Action
  - Stay and wait user at fixed location(and charging)
  - User inputs delivery command
  - Move to destination, complete mission and come back to station
- For Design 1
  - No delivery command / At fixed time
    - Move around a floor and spray disinfectant on the doorknob
- For Design 2
  - Detect human and check recipient when executing delivery
    - If detect recipient, hand over package without going destination and return

## Q&A

Thank you

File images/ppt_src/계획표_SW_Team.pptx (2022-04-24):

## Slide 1

진행 목표 SW Team | | 3M | | | | | 4M | | | | | 5M
| | 1w | 2w | 3w | 4w | 5w | 1w | 2w | 3w | 4w | 5w | 1w | 2w | 3w | 4w | 5w
SLAM | Nuri building. 3rd floor
| Mapping
| Localization
| Landmark positioning (ex. room 320 -> ( x,y ))
| Global search based on wall following
Detection | Door & doorknob detection
| Collecting dataset & Learning
| Detect door & doorknob
| Get doorknob pose & mark on map
| Calculate robot pose for spraying disinfectant
Module’s algorithm | Total three modules
| Delivery
| Disinfection
| Cleaning
GUI | Depends on the module
| Disinfection, Cleaning
| Delivery

문석준
최석원

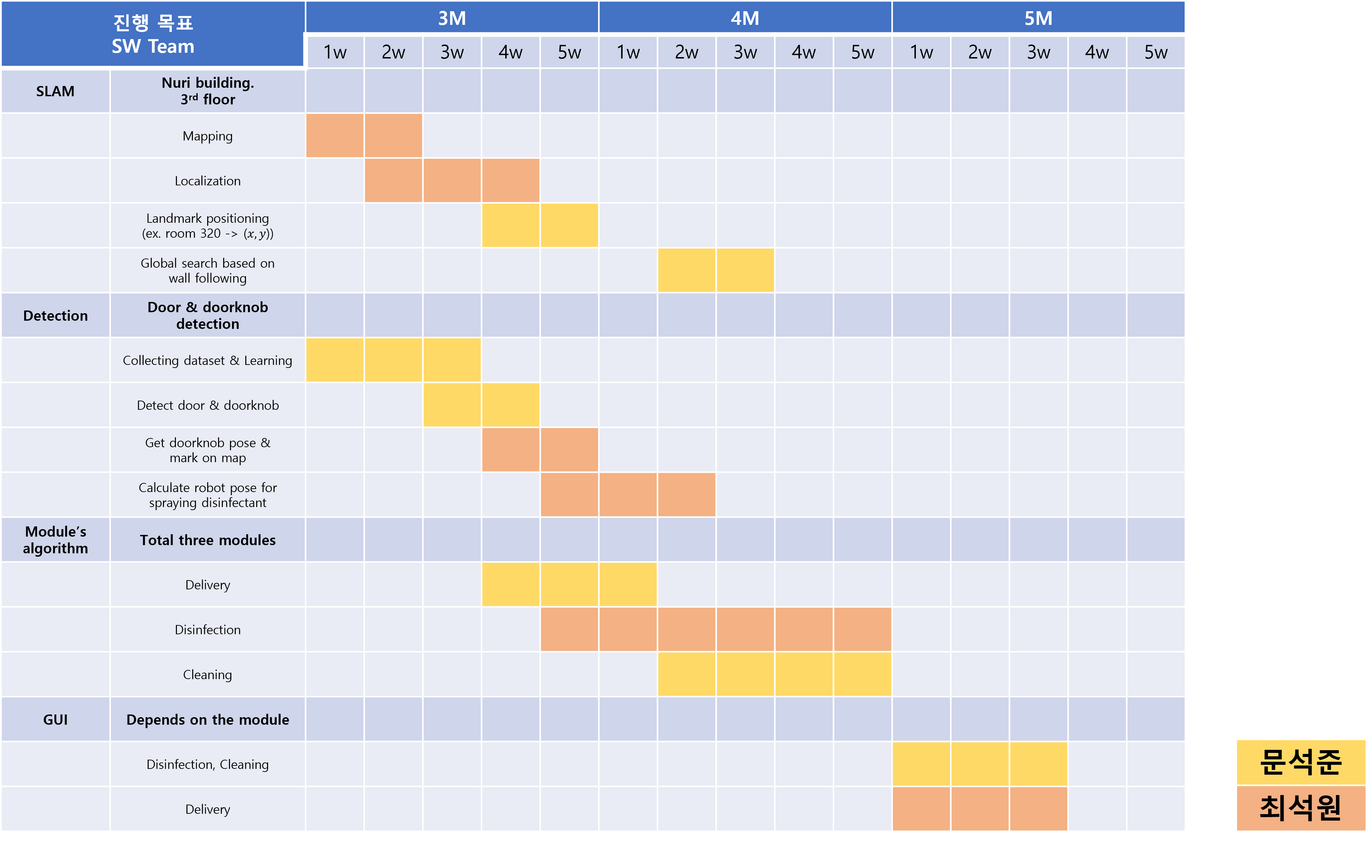
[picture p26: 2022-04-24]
images/ppt_src/계획표_SW_Team.png

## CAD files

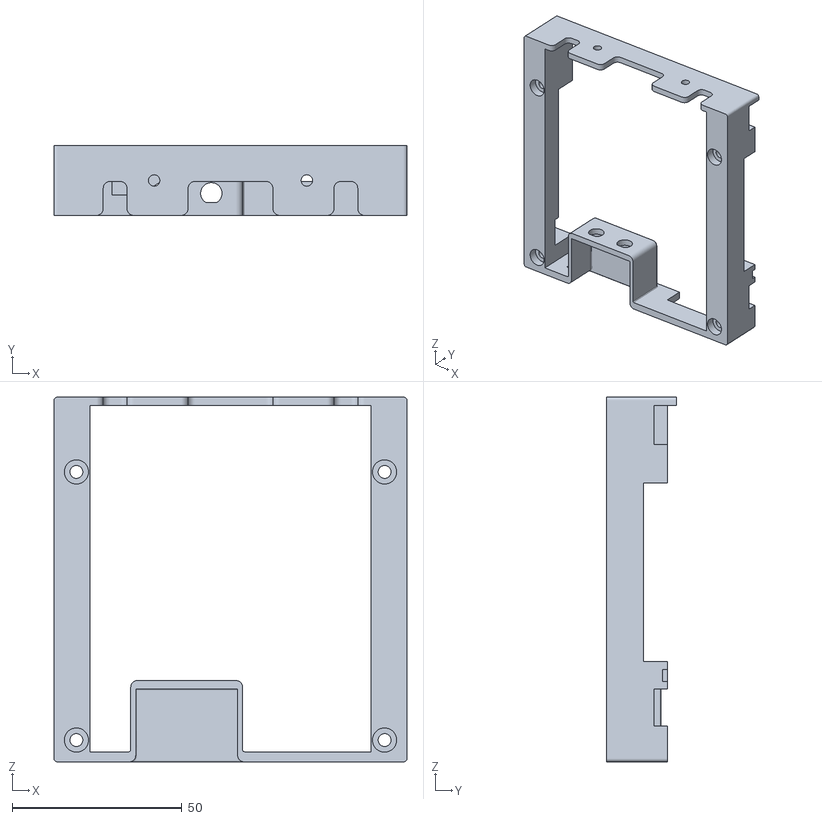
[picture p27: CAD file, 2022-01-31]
Reference files/Jetson AGX Xavier/base_xavier.STL
104.0 x 20.6 x 107.5

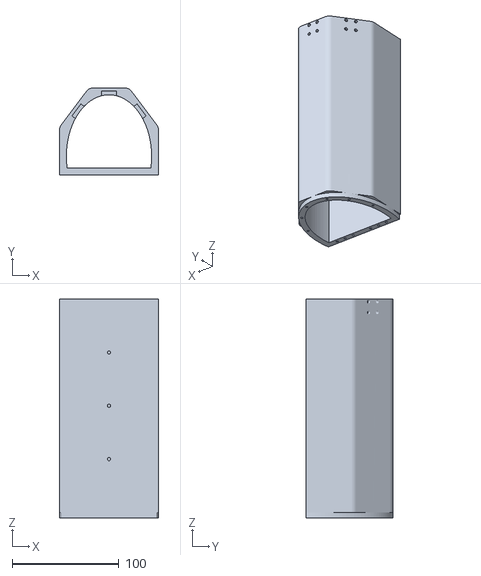
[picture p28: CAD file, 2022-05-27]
Reference files/Module model/방역위1 v2.stl
92.6 x 81.6 x 205.1

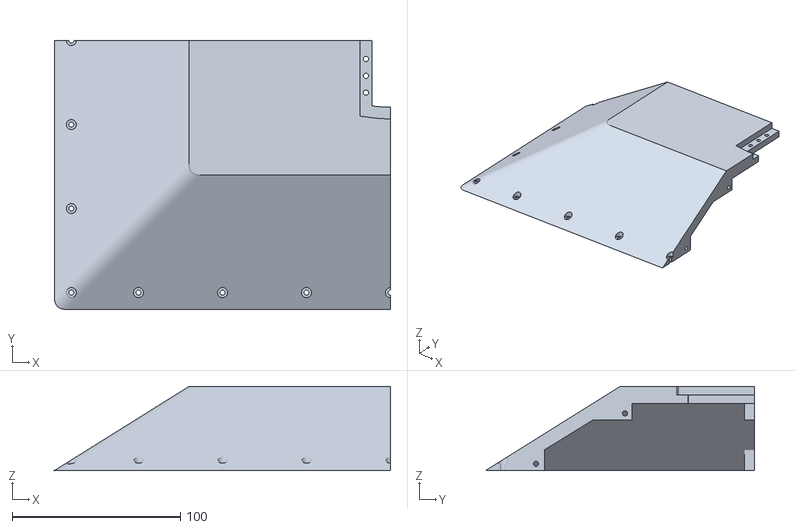
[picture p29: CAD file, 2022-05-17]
Reference files/Module model/방역모듈케이스4.stl
200.0 x 160.0 x 50.0

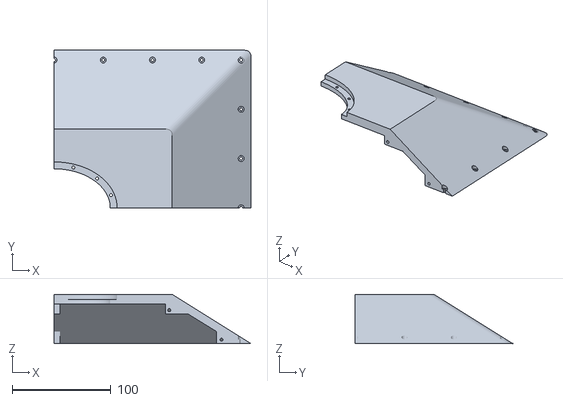
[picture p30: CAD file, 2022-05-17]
Reference files/Module model/방역모듈케이스1.stl
200.0 x 160.0 x 50.0

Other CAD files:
Reference files/Module model/방역모듈케이스3.stl
Reference files/Module model/방역모듈케이스2.stl

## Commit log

2022-01-30 Upload Jetson AGX Xavier cad model
2022-01-31 Update helpful for xavier
    [base_xavier.STL]
2022-04-24 Update original urdf
2022-05-17 Update 방역 모듈 3d 프린터 출력물
    [방역모듈케이스1.stl, 방역모듈케이스2.stl, 방역모듈케이스3.stl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]
2022-05-27 Update meeting
    [ICROS_학술대회_참가자명단_광운대학교(1610).xlsx, 방역위1 v2.stl]
2022-07-10 Update 한이음
